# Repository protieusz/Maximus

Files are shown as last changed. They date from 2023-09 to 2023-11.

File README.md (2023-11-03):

# Maximus as featured on https://kbd.news/Maximus-2124.html
Ieneko42c inspired keyboard with 38 keys and a 65mm Azoteq trackpad

Inspired by Ieneko42c by daraku__neko. Extra 2 mouse button keys are added as backup even though Azoteq can do gestures.
65mm trackpad makes a big difference compared to Ieneko42c 43mm trackpad. Operation is much smoother.
Keyboard is powered by Raspberry Pico RP2040, smd soldered to the pcb.  Diodes are also smd solder.

Print the pcb at your own risk. Tested but I am not responsible if it does not work on your end. No support will be provided. The build will require high level skills of soldering so be prepare.  I will make a build guide soon.

QMK source for the trackpad is copied from the original designer of ieneko42c. Please refer to his QMK code for more accuracy. I just copied and pasted his code into my Maximus. https://github.com/darakuneko/keyboard/tree/main/qmk/ieneko42c

# NOTE: 
Azoteq trackpads that you buy may sometimes have QA issues i.e. the solder pads at the back will come right off during soldering and trackpad themselves might be a dud. So it is better to order 2 trackpads just to be sure from your supplier. QMK support for Azoteq is not official yet
so the QMK code that I use is copied from the ieneko42c. Currently there is a PR for Azoteq for QMK and hopefully the code gets merged soon. Before flashing the Maximus QMK code that has the trackpad code in it, test it out by flashing the Maximussimple QMK code first after you soldered your 
diodes and mcu unit. Don't attach your trackpad yet. This Maximussimple code test will ensure that your pcb is working. Your pcb print should have no issues unless there was a quality defect from favorite pcb printing factory. If after flashing the Maximus QMK code with the trackpad code and,
the trackpad function or the pcb itself stop working then it is most likely the code itself or the trackpad issue. PCB in general should have no issue. Since the trackpad is not officially supported so there will be some weird fanicky issues so users will have to test it out. Like I said before, 
there are risk involve building this Maximus but it will work eventually.

Full Production Pictures





1BD20A9A-02A6-4801-B49B-B6780D1312E6

664B217D-1D70-4054-9D0C-97979DA8313F

D36E33E3-472A-439D-B128-F0F0E7C0B3B7





















# License

</a></p>

You are free to:

Share — copy and redistribute the material in any medium or format

Adapt — remix, transform, and build upon the material

The licensor cannot revoke these freedoms as long as you follow the license terms.
Under the following terms:

Attribution — You must give appropriate credit, provide a link to the license, and indicate if changes were made. You may do so in any reasonable manner, but not in any way that suggests the licensor endorses you or your use.

NonCommercial — You may not use the material for commercial purposes.

ShareAlike — If you remix, transform, or build upon the material, you must distribute your contributions under the same license as the original.

No additional restrictions — You may not apply legal terms or technological measures that legally restrict others from doing anything the license permits.

Maximus by ProtieusKeebs is licensed under [CC BY-NC-SA 4.0](https://creativecommons.org/licenses/by-nc-sa/4.0/?ref=chooser-v1)

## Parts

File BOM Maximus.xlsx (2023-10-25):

BOM for MAXIMUS |  | This is an assumption that you know how to medium to high level soldering skills to solder all the smd components together. If you skills are not up to par, this build might not be for you. Buy and build at your own risk.
1 | Azoteq TPS65 | https://www.mouser.ca/ProductDetail/Azoteq/TPS65-201A-S?qs=pfd5qewlna5Lh8O0E8DcUQ%3D%3D | Note: Azoteq has QA issues so it is better to order 2 so that if there is a dud, the chances of 2 dud is rare.
2 | Raspberry Pi Pico RP2040 | https://www.aliexpress.com/item/1005003371056277.html | Note: Pico Raspberry from AE is a hit and miss. Once you received the mcu, always check the
 |  | https://www.aliexpress.com/item/1005005905618001.html | USB C anchors. If there are no enough solder, solder secure it or else once you solder it to the
 |  |  | Maximus and you plug & unplug you are gonna get finicky results like a whole column not
 |  |  | working, etc. If possible get the original micro usb Raspberry Pi Pico. You have been warned!!!
3 | Flat Cable Connector (optional) | https://www.aliexpress.com/item/10000348360254.html | Get 0.5mm 6Pins. You would need high level smd soldering skills since the pins are a bitch to solder. Secure both sides of the connector with hot glue or some sort of glue
 |  |  | You can always solder wires from the trackpad pads to the pads on the pcb which is a backup option
4 | Flat Flexible Cable 0.5mm 6pins A-Positive Direction 10cm long | https://www.aliexpress.com/item/1005004514642405.html | Get what the title says for the spec from the link. Make sure it is A-Positive direction.
5 | Smd Diodes 1N4148 SOD-123 | https://www.aliexpress.com/item/1005001792457272.html

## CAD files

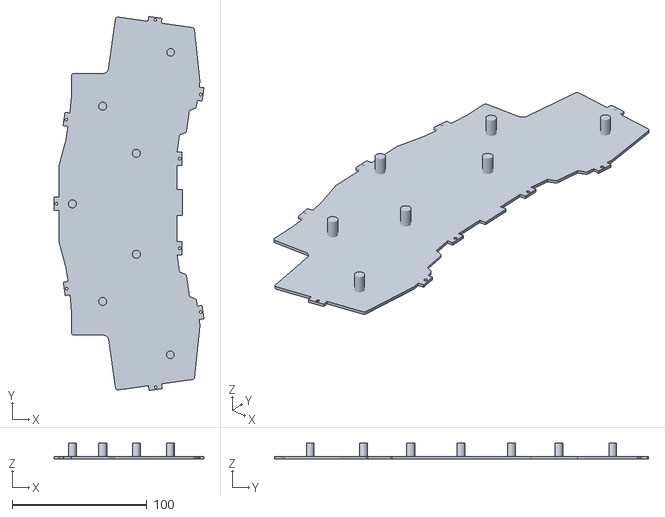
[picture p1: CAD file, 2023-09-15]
FullCase/MaximusTRS65FullBottom.stl
111.4 x 277.8 x 11.6

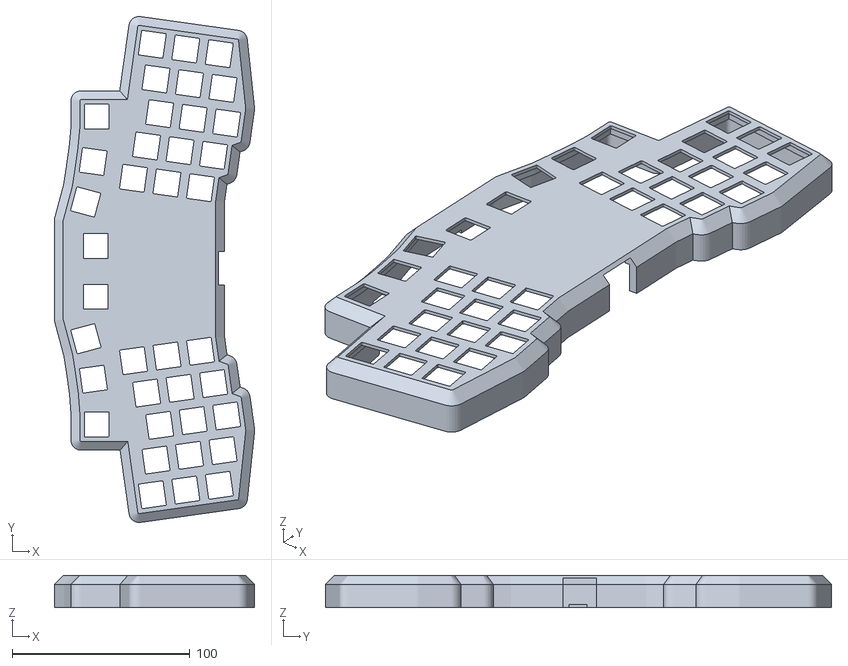
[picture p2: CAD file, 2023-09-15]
FullCase/MaximusTRS65FullCase.stl
112.8 x 284.9 x 18.1

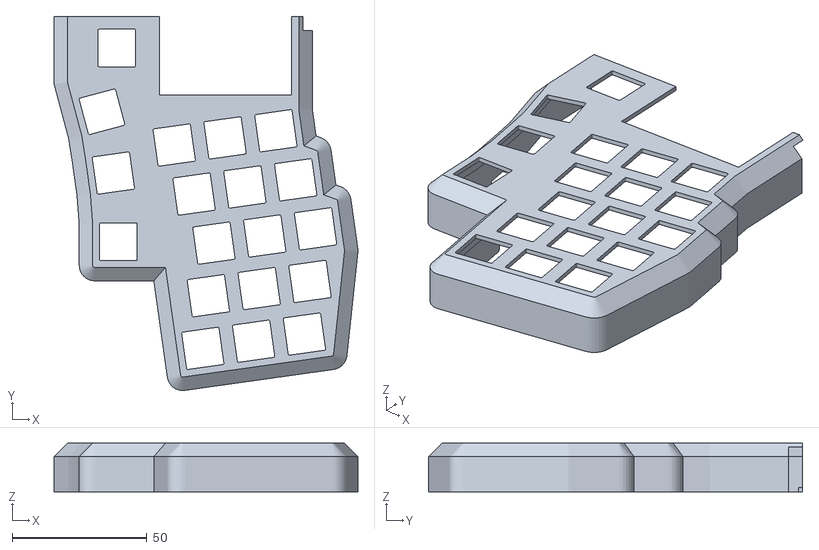
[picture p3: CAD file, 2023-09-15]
SplitCase/MaximusTPS65CaseRIGHT.stl
112.8 x 138.8 x 18.1

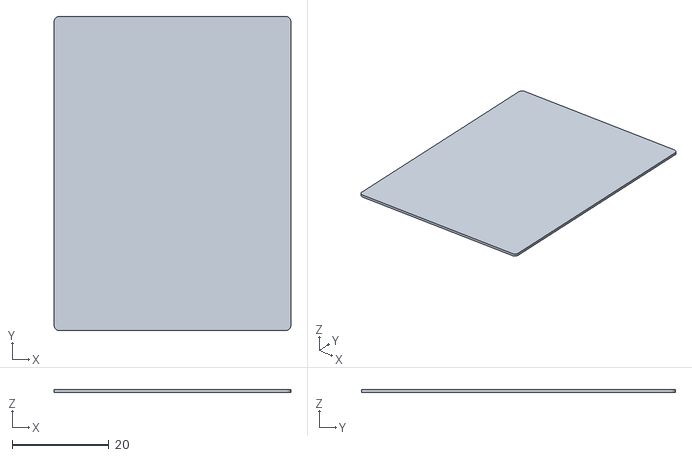
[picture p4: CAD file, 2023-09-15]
SplitCase/TPS65mmPinkOverlay.stl
49.0 x 65.0 x 0.6

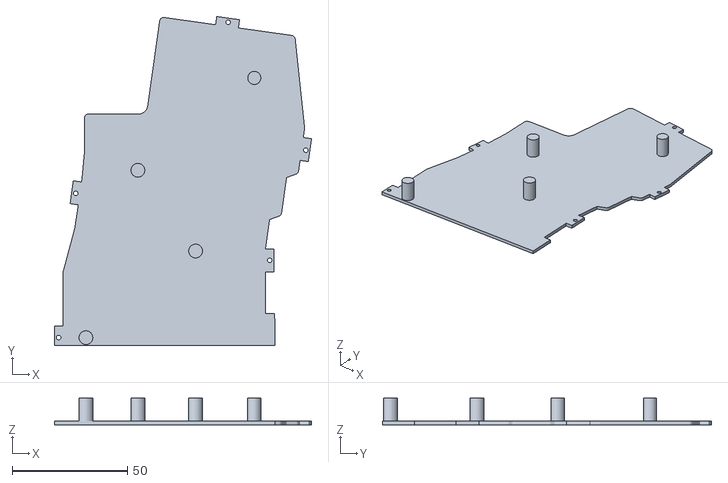
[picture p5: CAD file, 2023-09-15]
SplitCase/MaximusTPS65mmBottomLEFT.stl
111.4 x 142.5 x 11.5

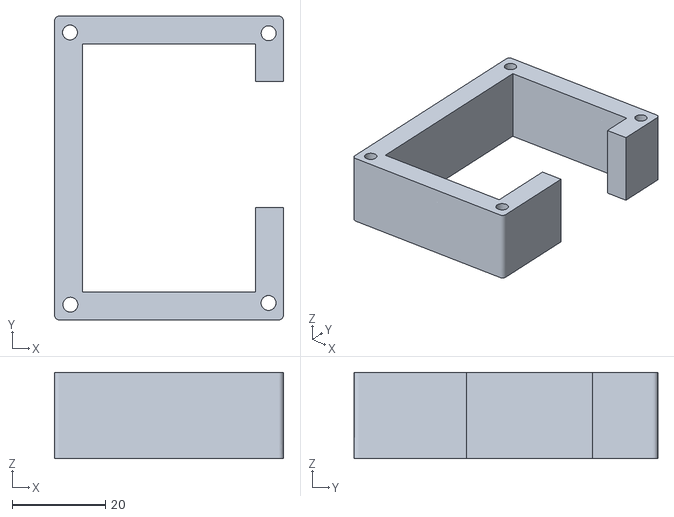
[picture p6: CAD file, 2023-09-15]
SplitCase/ScottoFlyTPS65SupportHoles.stl
49.0 x 65.0 x 18.5

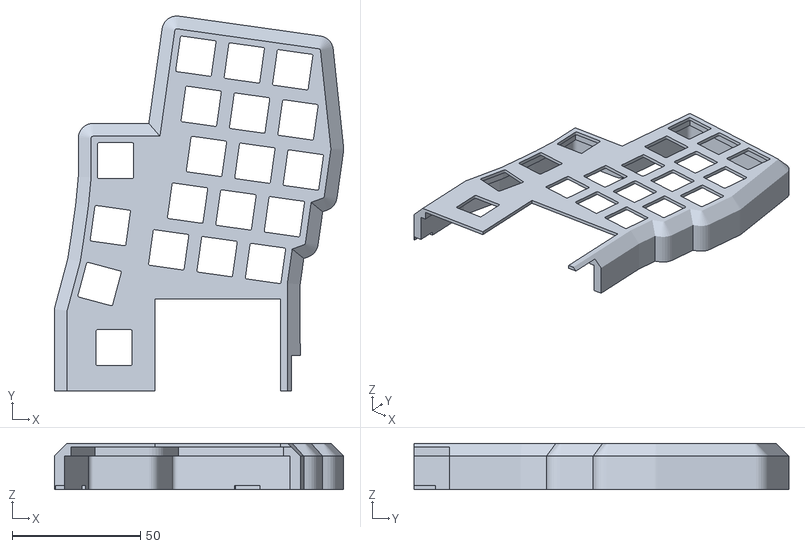
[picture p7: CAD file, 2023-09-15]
SplitCase/MaximusTPS65CaseLEFT.stl
112.8 x 146.1 x 18.1

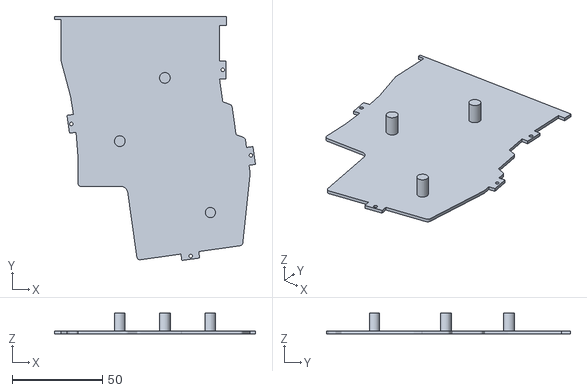
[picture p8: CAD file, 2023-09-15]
SplitCase/MaximusTPS65mmBottomRIGHT.stl
111.4 x 135.2 x 11.5

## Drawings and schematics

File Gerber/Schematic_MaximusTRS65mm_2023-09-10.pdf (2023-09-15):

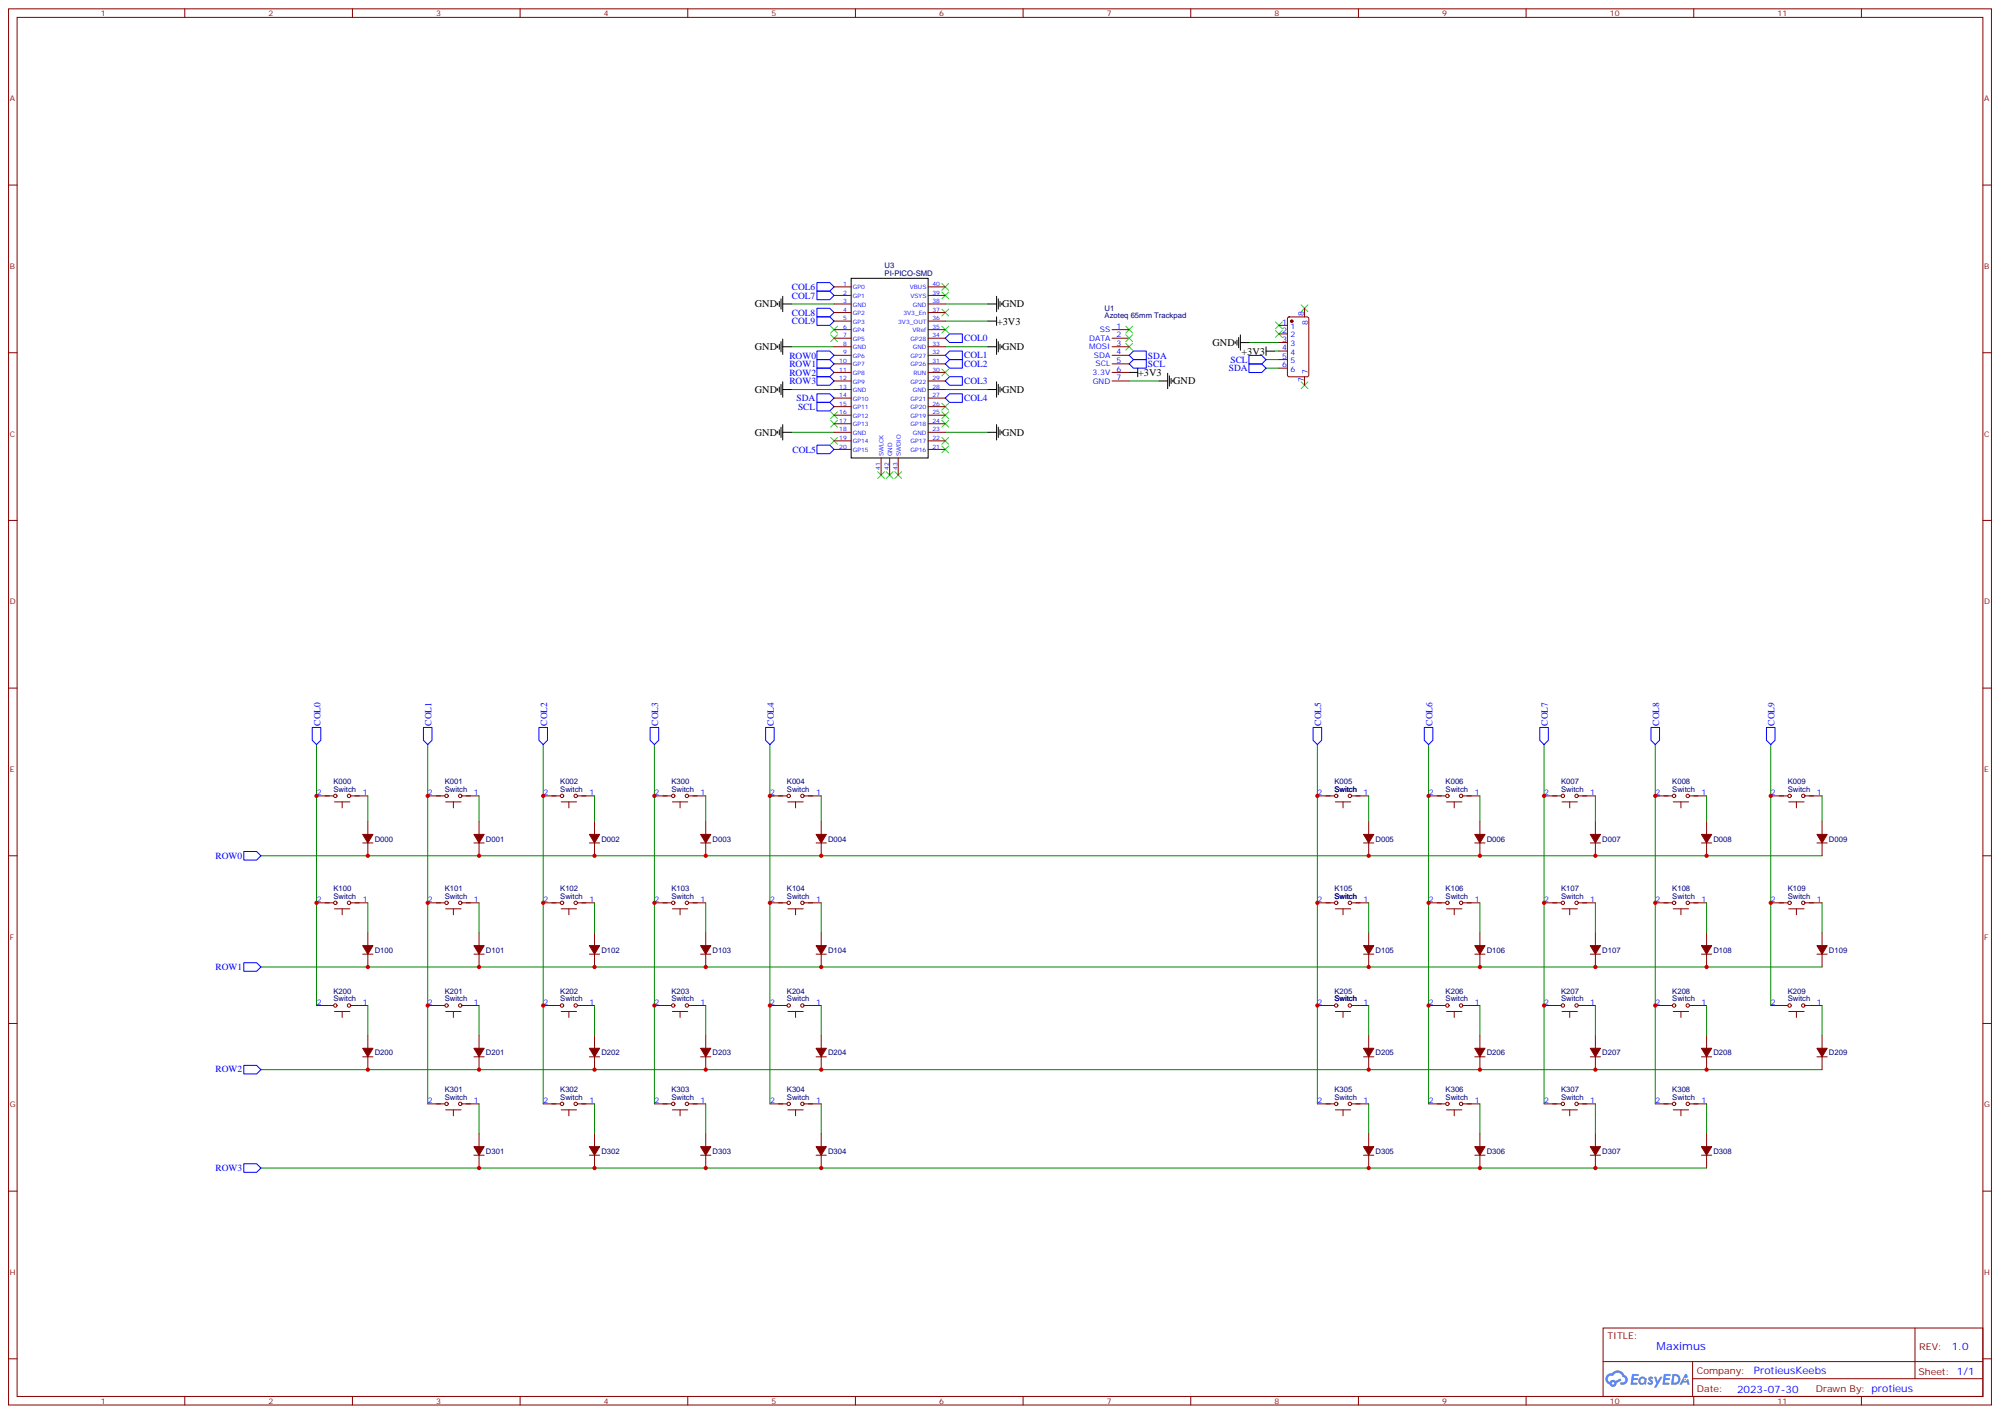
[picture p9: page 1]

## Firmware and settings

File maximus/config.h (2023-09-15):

#pragma once

#define RP2040_BOOTLOADER_DOUBLE_TAP_RESET // Activates the double-tap behavior
#define RP2040_BOOTLOADER_DOUBLE_TAP_RESET_TIMEOUT 200U // Timeout window in ms in which the double tap can occur.

#ifdef COMBO_ENABLE
#    define COMBO_COUNT 6
#    define COMBO_TERM 200
#endif

#define I2C1_SDA_PIN        GP10
#define I2C1_SCL_PIN        GP11

#define WS2812_DI_PIN GP6

/* Haptic feedback */
#define FB_ERM_LRA 0
#define FB_BRAKEFACTOR 3 // For 1x:0, 2x:1, 3x:2, 4x:3, 6x:4, 8x:5, 16x:6, Disable Braking:7
#define FB_LOOPGAIN 1 // For  Low:0, Medium:1, High:2, Very High:3
/* Motor settings */
#define RATED_VOLTAGE 3
#define V_PEAK 5
#define HAPTIC_FEEDBACK_DEFAULT 0
#define DRV_MODE_DEFAULT 0
#define DRV_GREETING       alert_750ms

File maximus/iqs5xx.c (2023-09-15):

/* Copyright 2020 sekigon-gonnoc
 *
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
 * You should have received a copy of the GNU General Public License
 * along with this program.  If not, see <http://www.gnu.org/licenses/>.
 */
#include "iqs5xx.h"
#include "quantum.h"
#include "drivers/haptic/DRV2605L.h"

uint16_t iqs_device_addr = IQS5xx_DEVICE_ADDR<<1;
static inline uint8_t iqs_app_readReg_continue(uint16_t regaddr, uint8_t* data, uint16_t len) {
    i2c_status_t status = i2c_readReg16(iqs_device_addr, regaddr, data, len, 100);
    return (status < 0) ? status : I2C_STATUS_SUCCESS;
}

static inline uint8_t iqs_app_end_communication(void) {
    uint8_t _ = 0xFF;
    return i2c_writeReg16(iqs_device_addr, IQS5xx_COM_END_REG, &_, 1, 100);
}

static inline uint8_t iqs_app_writeReg(uint16_t regaddr, uint8_t* data, uint16_t len) {
    uint8_t res = i2c_writeReg16(iqs_device_addr, regaddr, data, len, 100);
    res |= iqs_app_end_communication();

    return res;
}

void iqs_app_writeRegL(uint16_t regaddr, uint8_t* data, uint16_t len) {
    while (1) {
        uint8_t res = iqs_app_writeReg(regaddr, data, len);
        if (!res) {
            break;
        }
    }
}
    
//set absolutely
void init_iqs5xx(void) {
    uint16_t default_addr = IQS5xx_FINGER_NUM << 8;
    iqs_app_writeRegL(IQS5xx_DEFAULT_READ, (uint8_t*)&default_addr, sizeof(default_addr));
    uint8_t distance = 0x02;
    iqs_app_writeRegL(IQS5xx_ZOOM, &distance, 1);
}

bool read_iqs5xx(iqs5xx_data_t* const data) {
    uint8_t i2c_res = iqs_app_readReg_continue(IQS5xx_FINGER_NUM, &data->finger_cnt, 1);
    i2c_res |= iqs_app_readReg_continue(IQS5xx_GESTURE_EVENT0, &data->ges_evnet0, 1);
    i2c_res |= iqs_app_readReg_continue(IQS5xx_GESTURE_EVENT1, &data->ges_evnet1, 1);
    i2c_res |= iqs_app_readReg_continue(IQS5xx_RELATIVE_XY, (uint8_t*)&data->relative_xy, 4);
    i2c_res |= iqs_app_readReg_continue(IQS5xx_TOUCH_STRENGTH_FINGER_THREE, &data->touch_strenght_finger_three, 1);

    bool res = false;
    if (i2c_res != 0) {
        res = false;
    } else {
        iqs_app_end_communication();
        res = true;
    }

    return res;
}

int tapped3_cnt = 0;
void set_tap(iqs5xx_data_t* const data, report_mouse_t* const rep_mouse) {    
    if(tapped && data->finger_cnt == 0){
        rep_mouse->buttons &= ~(1 << (KC_BTN1 - KC_BTN1));
        clear_buttons = true;
        tapped = false;
        use_drag = false;
        return;  
    }

    if(data->finger_cnt == 0 && tapped3_cnt > FINGER_THREE_TAP_CNT){
        data->gesture = TAP_FINGER_THREE;
    }  

    if (data->ges_evnet0 == 1) {    
        rep_mouse->buttons |= (1 << (KC_BTN1 - KC_BTN1));
        tapped = true;
    } else if (timer_elapsed32(tap_time) > TAP_TERM && !use_drag && data->ges_evnet1 == 1) {
        rep_mouse->buttons |= (1 << (KC_BTN2 - KC_BTN1));
        tapped = true;
    } else if(can_drag && !use_drag && data->ges_evnet0 == 2) {
        if(drag_time == 0) {
            drag_time = timer_read32();
        } else if(timer_elapsed32(drag_time) > drag_term){
            DRV_pulse(hf_waveform_number); 
            use_drag = true;
            drag_time = 0;
            tapped = false;
        }
    } else if(data->touch_strenght_finger_three < 255 && data->ges_evnet1 == 0) {
        tapped3_cnt = tapped3_cnt + 1;
    } 

    if(rep_mouse->buttons || data->gesture == TAP_FINGER_THREE){
        tap_time = timer_read32();
    }
    
    if (use_drag){
        rep_mouse->buttons |= (1 << (KC_BTN1 - KC_BTN1));
    } else if(ms_key_status.is_pressed){
        rep_mouse->buttons |= (1 << (ms_key_status.keycode - KC_BTN1));
    }

    if(data->finger_cnt == 0){
        drag_time = 0;
        tapped3_cnt = 0;
    }   
}

void set_gesture(iqs5xx_data_t* const data, report_mouse_t* const rep_mouse) {
    uint32_t dx = ((data->relative_xy.bytes[1] - data->relative_xy.bytes[0]) / 2) * accel_speed;
    uint32_t dy = ((data->relative_xy.bytes[3] - data->relative_xy.bytes[2]) / 2) * accel_speed;
    if (data->finger_cnt == 1) {
        rep_mouse->x = dx;
        rep_mouse->y = dy;
    } else if (data->finger_cnt >= 2) {
        if(timer_elapsed32(swipe_time) > SWIPE_TERM && data->ges_evnet1 == 2 && data->finger_cnt == 2) {
            if(data->relative_xy.bytes[0] > 0 && data->relative_xy.bytes[1] > 0){
                data->gesture = GESTURE_SWIPE_L;
            } else if(data->relative_xy.bytes[1] > 0){
                data->gesture = GESTURE_SWIPE_R;
            } 

            swipe_time = timer_read32();
        } else if(timer_elapsed32(gesture_time) > GESTURE_TERM && data->ges_evnet1 == 2 && data->finger_cnt == 3) {
            if(data->relative_xy.bytes[0] > 0 && data->relative_xy.bytes[1] > 0){
                data->gesture = GESTURE_SWIPE_L;
            } else if(data->relative_xy.bytes[1] > 0){
                data->gesture = GESTURE_SWIPE_R;
            } else if(data->relative_xy.bytes[2] > 1 && data->relative_xy.bytes[3] > 1 ){
                data->gesture = GESTURE_SWIPE_D;
            } else if(data->relative_xy.bytes[3] > 1 ){
                data->gesture = GESTURE_SWIPE_U;
            }

            if(data->gesture == GESTURE_SWIPE_D || data->gesture == GESTURE_SWIPE_U){
                swipe_time = timer_read32();
            }
            gesture_time = timer_read32();
            tapped3_cnt = 0;
        } else if(timer_elapsed32(scroll_time) > scroll_term && data->ges_evnet1 == 2) {
            if(data->relative_xy.bytes[2] > 1 && data->relative_xy.bytes[3] > 1 ){
                rep_mouse->v = 1;
            } else if(data->relative_xy.bytes[3] > 1 ){
                rep_mouse->v = -1;
            } 
            scroll_time = timer_read32();
        } else if(timer_elapsed32(pinch_time) > PINCH_TERM && data->ges_evnet1 == 4) {
            if(data->relative_xy.bytes[0] > 0 && data->relative_xy.bytes[1] > 0) {
                data->gesture = GESTURE_PINCH_OUT;
            } else if(data->relative_xy.bytes[1] > 0) {
                data->gesture = GESTURE_PINCH_IN;
            }
            pinch_time = timer_read32();
        }
    }
}

void set_trackpad_layer(iqs5xx_data_t* const data) {
    if (data->finger_cnt == 0) {
        if(!ms_key_status.is_pressed && use_trackpad_layer && can_trackpad_layer){
            layer_move(get_highest_layer(default_layer_state));
            use_trackpad_layer = false;
        }
   } else {
        if(!ms_key_status.is_pressed && !use_trackpad_layer && can_trackpad_layer){
            layer_move(trackpad_layer);
            use_trackpad_layer = true;
        }
    }
}

void process_iqs5xx(iqs5xx_data_t* const data, report_mouse_t* const rep_mouse) {
    //debug
    //uprintf("finger: %d evnet0: %d  evnet1: %d\n", data->finger_cnt, data->ges_evnet0, data->ges_evnet1);

    set_trackpad_layer(data);
    set_gesture(data, rep_mouse);

    if(!data->gesture) {
        set_tap(data, rep_mouse);
    }
}

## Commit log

2023-09-15 Gerber & Schematic
2023-09-15 STL case
    [MaximusTRS65FullBottom.stl, MaximusTRS65FullCase.stl]
2023-09-15 Split Case, Trackpad Support & Overlay
    [MaximusTPS65CaseLEFT.stl, MaximusTPS65CaseRIGHT.stl, MaximusTPS65mmBottomLEFT.stl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]
2023-10-24 QMK Source for testing without trackpad code.
    Virgin QMK source code to make sure the basic function of the pcb works without the trackpad code.

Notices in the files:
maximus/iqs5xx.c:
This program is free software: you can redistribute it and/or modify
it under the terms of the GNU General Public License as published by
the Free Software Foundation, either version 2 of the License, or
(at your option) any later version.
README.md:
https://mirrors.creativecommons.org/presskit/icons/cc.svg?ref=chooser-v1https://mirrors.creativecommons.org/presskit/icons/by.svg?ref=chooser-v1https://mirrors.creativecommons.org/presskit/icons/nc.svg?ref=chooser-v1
